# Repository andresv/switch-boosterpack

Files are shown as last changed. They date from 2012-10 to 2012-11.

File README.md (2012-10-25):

## Switch Launchpad Boosterpack

This is boosterpack for MSP430 Launchpad. It has SSD1306 based 128x64 pixel OLED display and 4 power MOSFET outputs. It is meant for switching various loads - for example pneumatic actuators or relays.

Software is written using Energia: https://github.com/energia/Energia

## LICENSE
### Software
This work is licensed under MIT license. http://opensource.org/licenses/MIT
### Hardware
This work is licensed under version 3.0 of the Creative Commons CC-BY-SA license.
http://creativecommons.org/licenses/by-sa/3.0/

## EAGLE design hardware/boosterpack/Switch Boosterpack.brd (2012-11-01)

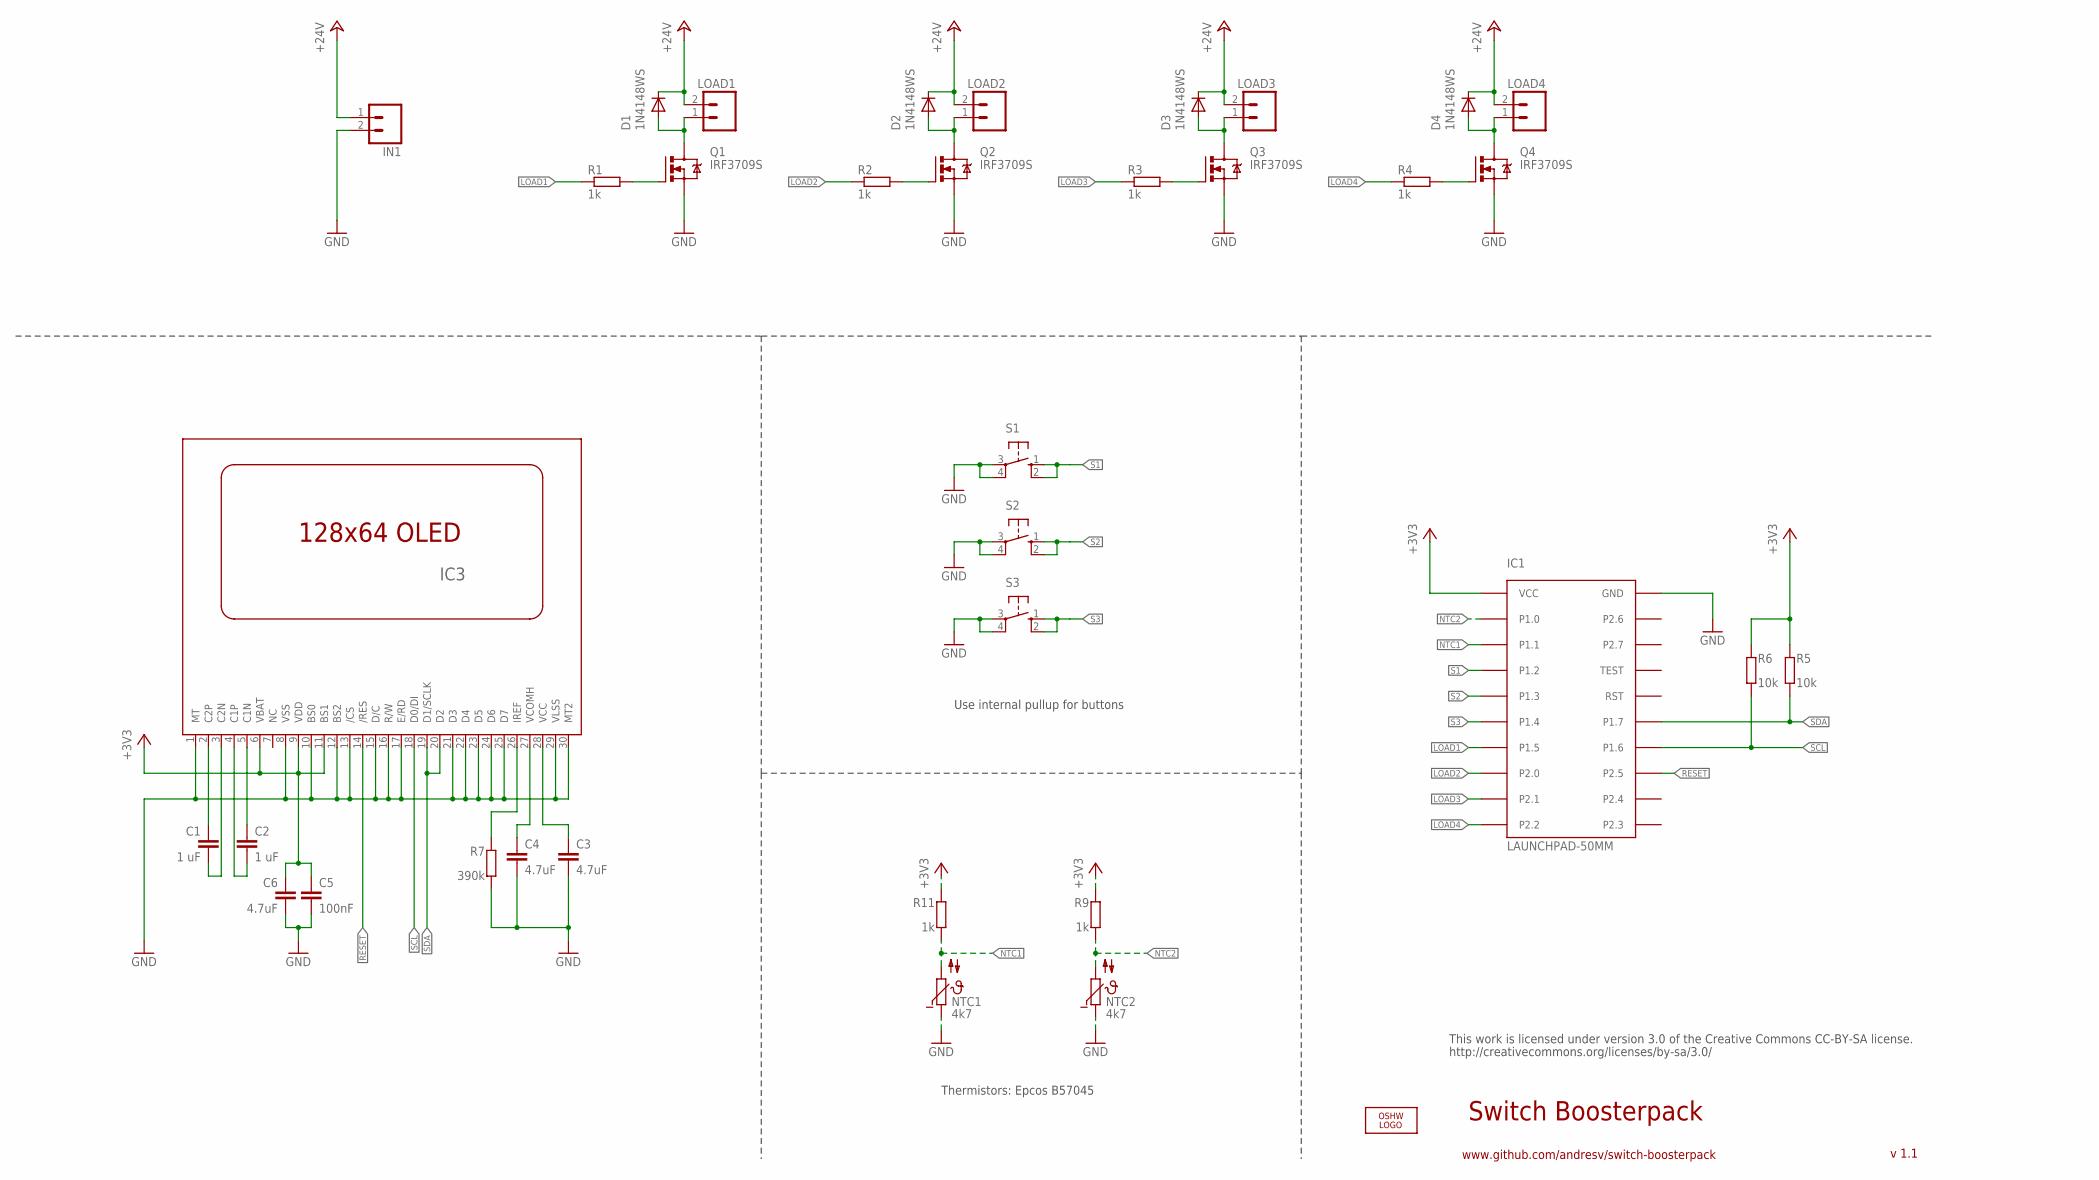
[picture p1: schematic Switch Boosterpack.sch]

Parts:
C1, C2: 1 uF; C0603
C3, C4, C6: 4.7uF; C0603
C5: 100nF; C0603
D1, D2, D3, D4: 1N4148WS; SOD323-W
IC1: LAUNCHPAD-50MM
IC3: UG-2864HSWEG01; 1X30-0.7MM
IN1: M025MM; SCREWTERMINAL-5MM-2
LOAD1, LOAD2, LOAD3, LOAD4: M025MM; SCREWTERMINAL-5MM-2
LOGO1: OSHW_LOGO_8MILX0350-NT; OSHW_8X350_NOTEXT
NTC1, NTC2: 4k7; N640
Q1, Q2, Q3, Q4: IRF3709S; D-PAK_TO252AA
R1, R2, R3, R4, R9, R11: 1k; R0603
R5, R6: 10k; R0603
R7: 390k; R0603
S1, S2, S3: 10-XX; B3F-10XX

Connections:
+3V3: C5.1, C6.1, IC1.VCC, IC3.6 (VBAT), IC3.9 (VDD), IC3.11 (BS1), R5.2, R6.2, R9.2, R11.2
+24V: D1.C, D2.C, D3.C, D4.C, IN1.1, LOAD1.2, LOAD2.2, LOAD3.2, LOAD4.2
GND: C3.2, C4.2, C5.2, C6.2, IC1.GND, IC3.1 (MT), IC3.8 (VSS), IC3.10 (BS0), IC3.12 (BS2), IC3.13 (/CS), IC3.15 (D/C), IC3.16 (R/W), IC3.17 (E/RD), IC3.21 (D3), IC3.22 (D4), IC3.23 (D5), IC3.24 (D6), IC3.25 (D7), IC3.29 (VLSS), IC3.30 (MT2), IN1.2, NTC1.1, NTC2.1, Q1.3 (S), Q2.3 (S), Q3.3 (S), Q4.3 (S), R7.1, S1.3, S1.4 (P1), S2.3, S2.4 (P1), S3.3, S3.4 (P1)
LOAD1: IC1.P1.5, R1.1
LOAD2: IC1.P2.0, R2.1
LOAD3: IC1.P2.1, R3.1
LOAD4: IC1.P2.2, R4.1
unnamed: D1.A, LOAD1.1, Q1.4 (D)
unnamed: Q1.1 (G), R1.2
unnamed: D2.A, LOAD2.1, Q2.4 (D)
unnamed: Q2.1 (G), R2.2
unnamed: D3.A, LOAD3.1, Q3.4 (D)
unnamed: Q3.1 (G), R3.2
unnamed: D4.A, LOAD4.1, Q4.4 (D)
unnamed: Q4.1 (G), R4.2
unnamed: C1.1, IC3.2 (C2P)
unnamed: C1.2, IC3.3 (C2N)
unnamed: C2.1, IC3.5 (C1N)
unnamed: C2.2, IC3.4 (C1P)
unnamed: C3.1, IC3.28 (VCC)
unnamed: C4.1, IC3.27 (VCOMH)
unnamed: IC3.26 (IREF), R7.2
NTC1: IC1.P1.1, NTC1.2, R11.1
NTC2: IC1.P1.0, NTC2.2, R9.1
RESET: IC1.P2.5, IC3.14 (/RES)
S1: IC1.P1.2, S1.1 (S), S1.2 (S1)
S2: IC1.P1.3, S2.1 (S), S2.2 (S1)
S3: IC1.P1.4, S3.1 (S), S3.2 (S1)
SCL: IC1.P1.6, IC3.18 (D0/DI), R6.1
SDA: IC1.P1.7, IC3.19 (D1/SCLK), IC3.20 (D2), R5.1

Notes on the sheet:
Switch Boosterpack
www.github.com/andresv/switch-boosterpack
v 1.1
This work is licensed under version 3.0 of the Creative Commons CC-BY-SA license.
http://creativecommons.org/licenses/by-sa/3.0/
Thermistors: Epcos B57045
Use internal pullup for buttons

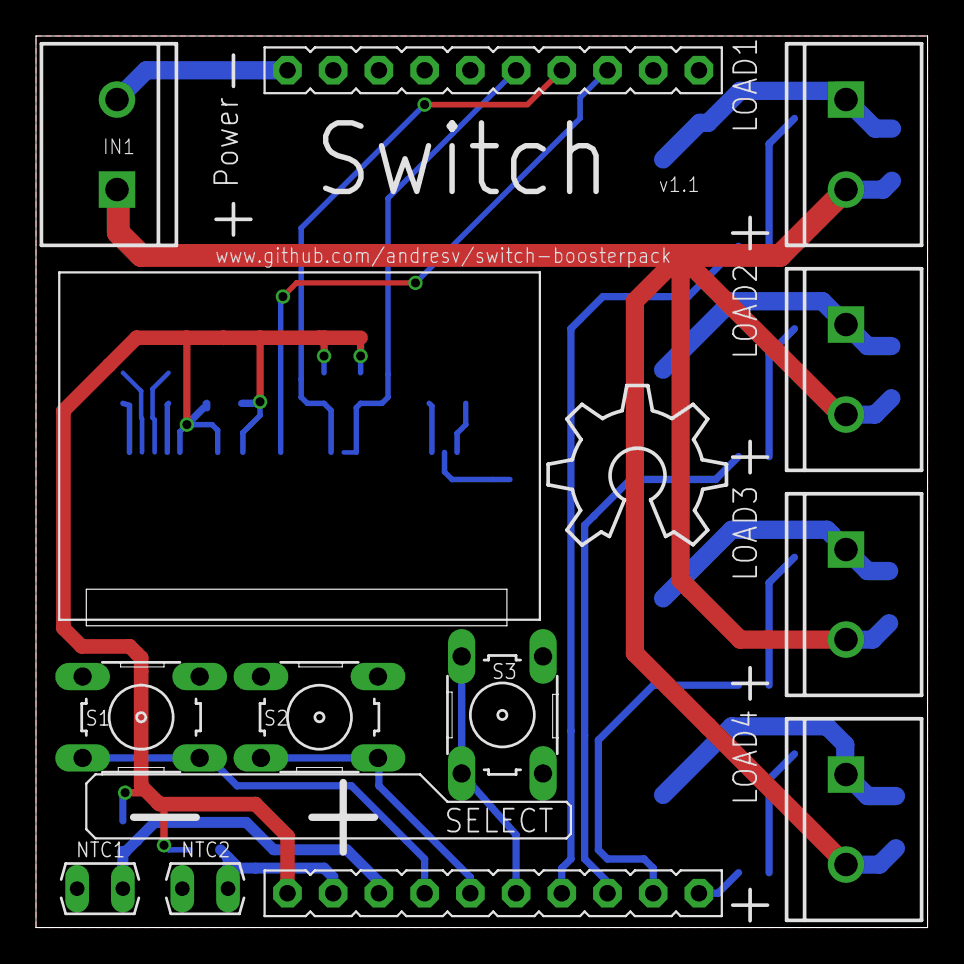
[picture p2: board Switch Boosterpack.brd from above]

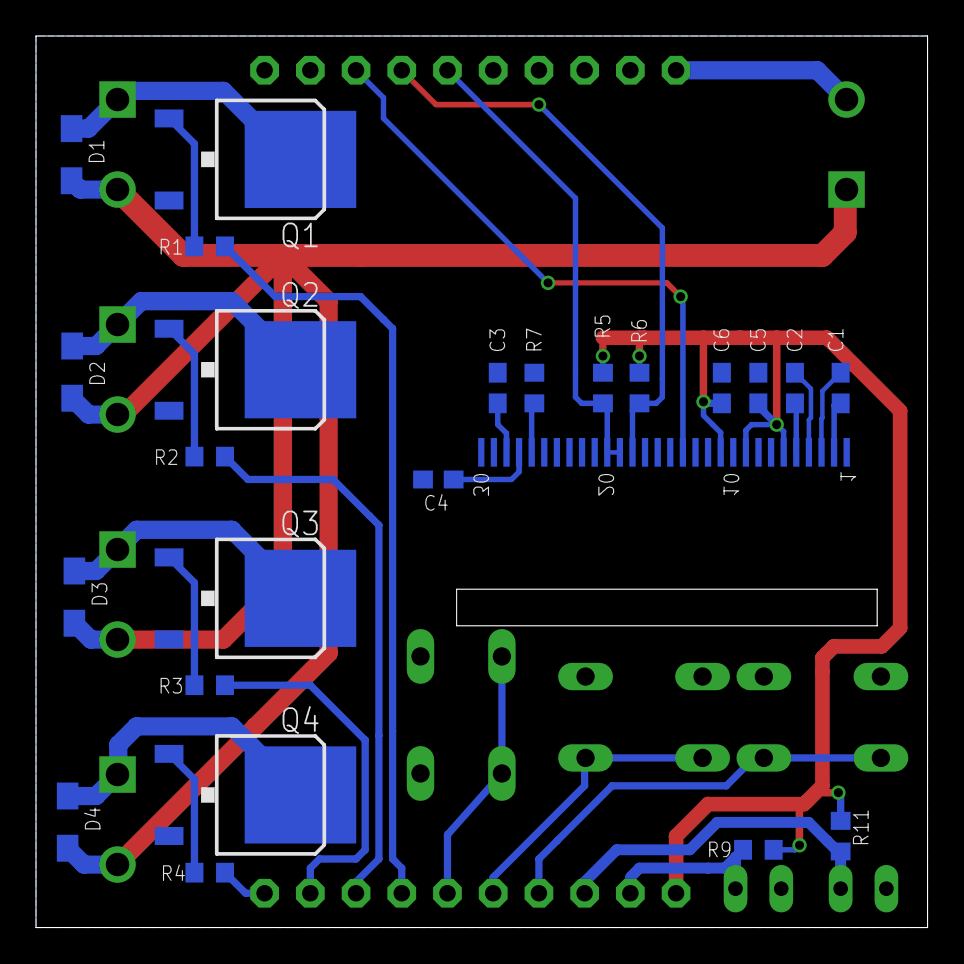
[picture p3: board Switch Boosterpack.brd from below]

Board: 2 copper layers, 49.5 x 49.5 mm, 36 parts (23 on the bottom side), 30 nets.

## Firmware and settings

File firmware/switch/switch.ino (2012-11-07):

/*
 * Copyright 2012 Andres Vahter
 * 
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
 * THE SOFTWARE IS PROVIDED "AS IS", WITHOUT WARRANTY OF ANY KIND,
 * EXPRESS OR IMPLIED, INCLUDING BUT NOT LIMITED TO THE WARRANTIES OF
 * MERCHANTABILITY, FITNESS FOR A PARTICULAR PURPOSE AND
 * NONINFRINGEMENT. IN NO EVENT SHALL THE AUTHORS OR COPYRIGHT HOLDERS BE
 * LIABLE FOR ANY CLAIM, DAMAGES OR OTHER LIABILITY, WHETHER IN AN ACTION
 * OF CONTRACT, TORT OR OTHERWISE, ARISING FROM, OUT OF OR IN CONNECTION
 * WITH THE SOFTWARE OR THE USE OR OTHER DEALINGS IN THE SOFTWARE.
 */

#include <Energia.h>
#include "MspFlash.h"
#include <stdlib.h>
#include "OLED.h"

#define TRUE 1
#define FALSE 0
#define ON 1
#define OFF 0

//https://github.com/energia/Energia/blob/master/hardware/msp430/libraries/MspFlash/examples/flash_readwrite/flash_readwrite.ino
#define flash SEGMENT_D

#define PLUS_BUTTON 4
#define MINUS_BUTTON 5
#define SELECT_BUTTON 6
#define LOAD1 7
#define LOAD2 8
#define LOAD3 9
#define LOAD4 10

#define NUMTEMPS 103 // NTC table
#define ROLLING_AVERAGE_SIZE 10

#define UPPER_HYSTERESIS 5
#define LOWER_HYSTERESIS 5

OLED oled(13, 0x3C);

int8_t current_temp_1;
int8_t set_temp_1;
int8_t current_temp_2;
int8_t set_temp_2;

uint16_t temp_1_rolling_buf[ROLLING_AVERAGE_SIZE];
uint16_t temp_2_rolling_buf[ROLLING_AVERAGE_SIZE];

bool hysteresis_1_raising = TRUE;
bool hysteresis_2_raising = TRUE;

uint8_t relay_states = 0; //0b000x xxx0

enum {
    STATE_DISPLAY,
    STATE_PLUS_BUTTON_PRESSED,
    STATE_MINUS_BUTTON_PRESSED,
    STATE_SELECT_BUTTON_PRESSED,
};

enum {
    MODE_DISPLAY,
    MODE_SET_1,
    MODE_SET_2,
};

uint8_t state = STATE_DISPLAY;
uint8_t mode = MODE_DISPLAY;
bool show_dot = 1;

// https://raw.github.com/reprap/firmware/master/createTemperatureLookup.py
// python createTemperatureLookup.py --r0=4700 --t0=25 --r1=0 --r2=1000 --beta=3950 --max-adc=1023
//      num steps were manualy set to 100 and adcref to 3.6 V
// http://hydraraptor.blogspot.com/2007/10/measuring-temperature-easy-way.html
// NTC 4.7k EPCOS B57045-K472-K

const short temptable[NUMTEMPS][2] = {
   {1, 554},
   {11, 277},
   {21, 231},
   {31, 206},
   {41, 190},
   {51, 178},
   {61, 168},
   {71, 160},
   {81, 154},
   {91, 148},
   {101, 143},
   {111, 138},
   {121, 134},
   {131, 130},
   {141, 127},
   {151, 123},
   {161, 120},
   {171, 118},
   {181, 115},
   {191, 113},
   {201, 110},
   {211, 108},
   {221, 106},
   {231, 104},
   {241, 102},
   {251, 100},
   {261, 98},
   {271, 96},
   {281, 95},
   {291, 93},
   {301, 91},
   {311, 90},
   {321, 88},
   {331, 87},
   {341, 85},
   {351, 84},
   {361, 82},
   {371, 81},
   {381, 80},
   {391, 78},
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
};

int convert_raw_to_celsius(int rawtemp) {
    int current_celsius = 0;
    int i = 0;

    for (i=1; i < NUMTEMPS; i++) {
        if (temptable[i][0] > rawtemp) {
            int realtemp  = temptable[i-1][1] + (rawtemp - temptable[i-1][0]) * (temptable[i][1] - temptable[i-1][1]) / (temptable[i][0] - temptable[i-1][0]);
            if (realtemp > 255) {
                realtemp = 255;
            }

            current_celsius = realtemp;
            break;
        }
    }

    // Overflow: We just clamp to 0 degrees celsius
    if (i == NUMTEMPS)  {
        current_celsius = 1000;
    }

    return current_celsius;
}

inline uint16_t calc_average(uint16_t* buf, bool filled) {
    if (filled) {
        uint8_t i;
        uint16_t sum = 0;
        for (i=0; i<ROLLING_AVERAGE_SIZE; i++) {
            sum += buf[i];
        }
        return sum/ROLLING_AVERAGE_SIZE;
    }
    else {
        return buf[0];
    }
}

uint16_t temp_1_rolling_average(uint16_t rawtemp) {
    static uint8_t index = 0;
    static bool filled = FALSE;

    temp_1_rolling_buf[index] = rawtemp;
    index++;
    if (index == ROLLING_AVERAGE_SIZE) {
        index = 0;
        filled = TRUE;
    }

    return calc_average(temp_1_rolling_buf, filled);
}

uint16_t temp_2_rolling_average(uint16_t rawtemp) {
    static uint8_t index = 0;
    static bool filled = FALSE;

    temp_2_rolling_buf[index] = rawtemp;
    index++;
    if (index == ROLLING_AVERAGE_SIZE) {
        index = 0;
        filled = TRUE;
    }

    return calc_average(temp_2_rolling_buf, filled);
}

int read_temp_1() {
    uint16_t rawtemp = analogRead(A1);
    return convert_raw_to_celsius(temp_1_rolling_average(rawtemp));
}

int read_temp_2() {
    uint16_t rawtemp = analogRead(A0);
    return convert_raw_to_celsius(temp_2_rolling_average(rawtemp));
}

void read_temp_sensors() {
    current_temp_1 = read_temp_1();
    oled.set_cursor(10, 5, LARGE_FONT);
    oled.write("%3i %3i", current_temp_1, set_temp_1);
    
    current_temp_2 = read_temp_2();
    oled.set_cursor(10, 2, LARGE_FONT);
    oled.write("%3i %3i", current_temp_2, set_temp_2);
}

void display_relay_state(uint8_t relay_nr, bool on) {
    if (on) {
        relay_states |= (1<<relay_nr);
        oled.write("o");
    }
    else {
        relay_states &= ~(1<<relay_nr);
        oled.write(".");
    }
}

void switch_relay(uint8_t relay_nr, bool on) {
    // Notice that LOAD outputs are inverted
    // LOW is ON
    // HIGH is OFF
    // Thats why there is such a 'nice' bit twiddling
    switch (relay_nr) {
        case 1:
            oled.set_cursor(120, 7, SMALL_FONT);
            display_relay_state(relay_nr, on);
            digitalWrite(LOAD1, ((relay_states ^ (1 << 1)) >> 1) & 0x01);
            break;
        case 2:
            oled.set_cursor(120, 5, SMALL_FONT);
            display_relay_state(relay_nr, on);
            digitalWrite(LOAD2, ((relay_states ^ (1 << 2)) >> 2) & 0x01);
            break;
        case 3:
            oled.set_cursor(120, 3, SMALL_FONT);
            display_relay_state(relay_nr, on);
            digitalWrite(LOAD3, ((relay_states ^ (1 << 3)) >> 3) & 0x01);
            break;
        case 4:
            oled.set_cursor(120, 1, SMALL_FONT);
            display_relay_state(relay_nr, on);
            digitalWrite(LOAD4, ((relay_states ^ (1 << 4)) >> 4) & 0x01);
            break;
    }
}

void save_set_values() {
    int8_t buf[2] = {set_temp_1, set_temp_2};
    Flash.erase(flash);
    Flash.write(flash, (unsigned char*)buf, 2);
}

void restore_set_values() {
    Flash.read(flash, (unsigned char*)&set_temp_1, 1);
    Flash.read(flash+1, (unsigned char*)&set_temp_2, 1);
}

void setup() {
    restore_set_values();

    oled.init();
    oled.clear();
    
    oled.set_cursor(15, 7, SMALL_FONT);
    oled.write("current       set");

    oled.set_cursor(10, 5, LARGE_FONT);
    oled.write("%3i %3i", current_temp_1, set_temp_1);

    oled.set_cursor(10, 2, LARGE_FONT);
    oled.write("%3i %3i", current_temp_2, set_temp_2);

    pinMode(LOAD1, OUTPUT);
    pinMode(LOAD2, OUTPUT);
    pinMode(LOAD3, OUTPUT);
    pinMode(LOAD4, OUTPUT);
    switch_relay(1, OFF);
    switch_relay(2, OFF);
    switch_relay(3, OFF);
    switch_relay(4, OFF);
    
    pinMode(PLUS_BUTTON, INPUT_PULLUP);
    pinMode(MINUS_BUTTON, INPUT_PULLUP);
    pinMode(SELECT_BUTTON, INPUT_PULLUP);

    pinMode(A0, INPUT);
    pinMode(A1, INPUT);
}

void loop() {
    read_temp_sensors();

    if (digitalRead(PLUS_BUTTON) == LOW) {
        state = STATE_PLUS_BUTTON_PRESSED;
        delay(10);
    }
    else if (digitalRead(MINUS_BUTTON) == LOW) {
        state = STATE_MINUS_BUTTON_PRESSED;
        delay(10);
    }
    else if (digitalRead(SELECT_BUTTON) == LOW) {
        state = STATE_SELECT_BUTTON_PRESSED;
        delay(10);
    }

    switch(state) {
        case STATE_PLUS_BUTTON_PRESSED:
            if (mode == MODE_SET_1) {
                set_temp_1++;
            }
            else if (mode == MODE_SET_2) {
                set_temp_2++;
            }
            state = STATE_DISPLAY;
            break;

        case STATE_MINUS_BUTTON_PRESSED:
            if (mode == MODE_SET_1) {
                set_temp_1--;
            }
            else if (mode == MODE_SET_2) {
                set_temp_2--;
            }
            state = STATE_DISPLAY;
            break;

        case STATE_SELECT_BUTTON_PRESSED:
            if (mode == MODE_DISPLAY) {
                mode = MODE_SET_1;
            }
            else if (mode == MODE_SET_1) {
                mode = MODE_SET_2;
            }
            else {
                save_set_values();
                mode = MODE_DISPLAY;
            }

            delay(500); // wait a little, otherwise we might get back to MODE_SET_1 too soon

            state = STATE_DISPLAY;
            break;

        case STATE_DISPLAY:
            // show blinking dot
            oled.set_cursor(0, 7, SMALL_FONT);
            if (show_dot == 1) {
                show_dot = 0;
                oled.write(" ");
            }
            else {
                show_dot = 1;
                oled.write(".");
            }

            // show temperatures
            if (mode == MODE_SET_1) {
                oled.set_cursor(10, 5, LARGE_FONT);
                oled.write("%3i    ", current_temp_1);
                oled.set_cursor(10, 5, LARGE_FONT);
                oled.write("%3i %3i", current_temp_1, set_temp_1);
            }
            else if (mode == MODE_SET_2) {
                oled.set_cursor(10, 2, LARGE_FONT);
                oled.write("%3i    ", current_temp_2);
                oled.set_cursor(10, 2, LARGE_FONT);
                oled.write("%3i %3i", current_temp_2, set_temp_2);
            }

            //---------------------------------------------------------------
            // 1 ON-OFF regulator
            //---------------------------------------------------------------
            // upper point
            if (hysteresis_1_raising && (current_temp_1 >= (set_temp_1 + UPPER_HYSTERESIS))) {
                hysteresis_1_raising = FALSE;
            }
            // lower point
            else if (!hysteresis_1_raising && (current_temp_1 <= (set_temp_1 - LOWER_HYSTERESIS))) {
                hysteresis_1_raising = TRUE;
            }
            // raising
            if (hysteresis_1_raising) {
                switch_relay(1, ON);
                switch_relay(2, ON);
            }
            // falling
            else {
                switch_relay(1, OFF);
                switch_relay(2, OFF);
            }

            //---------------------------------------------------------------
            // 2 ON-OFF regulator
            //---------------------------------------------------------------
            // upper point
            if (hysteresis_2_raising && (current_temp_2 >= (set_temp_2 + UPPER_HYSTERESIS))) {
                hysteresis_2_raising = FALSE;
            }
            // lower point
            else if (!hysteresis_2_raising && (current_temp_2 <= (set_temp_2 - LOWER_HYSTERESIS))) {
                hysteresis_2_raising = TRUE;
            }
            // raising
            if (hysteresis_2_raising) {
                switch_relay(3, ON);
                switch_relay(4, ON);
            }
            // falling
            else {
                switch_relay(3, OFF);
                switch_relay(4, OFF);
            }

            break;
    }
}

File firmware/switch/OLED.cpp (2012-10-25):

/*
 * Copyright 2012 Andres Vahter
 * 
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
 * THE SOFTWARE IS PROVIDED "AS IS", WITHOUT WARRANTY OF ANY KIND,
 * EXPRESS OR IMPLIED, INCLUDING BUT NOT LIMITED TO THE WARRANTIES OF
 * MERCHANTABILITY, FITNESS FOR A PARTICULAR PURPOSE AND
 * NONINFRINGEMENT. IN NO EVENT SHALL THE AUTHORS OR COPYRIGHT HOLDERS BE
 * LIABLE FOR ANY CLAIM, DAMAGES OR OTHER LIABILITY, WHETHER IN AN ACTION
 * OF CONTRACT, TORT OR OTHERWISE, ARISING FROM, OUT OF OR IN CONNECTION
 * WITH THE SOFTWARE OR THE USE OR OTHER DEALINGS IN THE SOFTWARE.
 */


/*
 * This driver is based on www.43oh.com 128x64 OLED Booster Pack driver:
 * http://www.43oh.com/2011/11/the-terminal-128x64-oled-booster-pack/
 *
 * Original driver is heaviliy modified by Andres Vahter in order to work
 * with Energia environment and with I2C protocol.
*/

#include <Energia.h>
#include <Wire.h>
#include "OLED.h"
#include "CourierNew_14x15.h"
#include "CourierNew_5x7.h"

OLED::OLED(uint8_t reset_pin, uint8_t i2c_address) {
    p_reset_pin = reset_pin;
    p_i2c_address = i2c_address;

    p_row = 0;
    p_column = 0;
    p_column_increment_small_font = 0;
    p_column_increment_large_font = 0;
    p_column_increment_flag = NO_FONT;

    //      4294967296      // 32 bit unsigned max
    dv[0] = 1000000000;     // +0
    dv[1] =  100000000;     // +1
    dv[2] =   10000000;     // +2
    dv[3] =    1000000;     // +3
    dv[4] =     100000;     // +4
    //           65535      // 16 bit unsigned max     
    dv[5] =      10000;     // +5
    dv[6] =       1000;     // +6
    dv[7] =        100;     // +7
    dv[8] =         10;     // +8
    dv[9] =          1;     // +9
        
}

void OLED::init() {
    pinMode(p_reset_pin, OUTPUT);
    digitalWrite(p_reset_pin, HIGH);
    delay(100);

    Wire.begin();

    digitalWrite(p_reset_pin, HIGH);
    // VDD (3.3V) goes high at start, lets just chill for a ms
    delay(1);
    digitalWrite(p_reset_pin, LOW);
    delay(10);
    digitalWrite(p_reset_pin, HIGH);

    send_command(0xae); // turn off oled panel 
    send_command(0x00); // set low column address 
    send_command(0x10); // set high column address 
    send_command(0x40); // set start line address 
    send_command(0x81); // set contrast control register 
    send_command(0xcf); 
    send_command(0xa1); // set segment re-map 95 to 0 
    send_command(0xa6); // set normal display 
    send_command(0xa8); // set multiplex ratio(1 to 64) 
    send_command(0x3f); // 1/64 duty 
    send_command(0xd3); // set display offset 
    send_command(0x00); // not offset 
    send_command(0xd5); // set display clock divide ratio/oscillator frequency 
    send_command(0x80); // set divide ratio 
    send_command(0xd9); // set pre-charge period 
    send_command(0xf1); 
    send_command(0xda); // set com pins hardware configuration 
    send_command(0x12); 
    send_command(0xdb); // set vcomh 
    send_command(0x40); 
    send_command(0x8d); // set Charge Pump enable/disable 
    send_command(0x14); // set(0x10) disable 
    send_command(0xaf); // turn on oled panel
    
    clear();            // Clear Screen
}

void OLED::clear() {
    fill_ram(0x00);
}

void OLED::set_cursor(uint8_t column, uint8_t row, uint8_t size_flag) {
    p_row = row;
    p_column_increment_flag = size_flag;
  
    if (p_column_increment_flag == SMALL_FONT)
        p_column_increment_small_font = column;
  
    if (p_column_increment_flag == LARGE_FONT)
        p_column_increment_large_font = column;
}

void OLED::write(char *format, ...) {
    char c;
    int i, val;
    int8_t padding_len;
    long n;
    
    va_list a;
    va_start(a, format);
    while (c = *format++) {
        if (c == '%') {
            c = *format++;
            // '1' is 49 '2' is 50 .. '9' is 57
            // '1' - 48 = 0x01 which is real number, not ASCII number
            padding_len = c-48;
            // we found padding so now check format string type
            if ((uint8_t)padding_len >= 1 && (uint8_t)padding_len <= 9) {
                c = *format++;
            }

            switch (c) {
                case 's':                       // String
                    puts(va_arg(a, char*));
                    break;
                case 'c':                       // Char
                    putc(va_arg(a, char));
                    break;
                case 'i':                       // 16 bit Integer
                case 'd':                       // 16 bit Integer
                case 'u':                       // 16 bit Unsigned
                    i = va_arg(a, int);
                    if ((uint8_t)padding_len >= 1 && (uint8_t)padding_len <= 9) {
                        val = i;
                        while (val != 0) {
                            val = val / 10;
                            padding_len--;
                        }

                        if (padding_len > 0) {
                            if (i <= 0) {
                                padding_len--; // - sign already pads 1 place and 0 is special
                            }

                            for (int i = 0; i < (uint8_t)padding_len; ++i) {
                                putc(' ');
                            }
                        }
                    }

                    if (c == 'i' && i < 0) {
                        i = -i;
                        putc('-');
                    }

                    xtoa((unsigned)i, dv + 5);
                    break;
                case 'l':                       // 32 bit Long
                case 'n':                       // 32 bit uNsigned loNg
                    n = va_arg(a, long);
                    if (c == 'l' &&  n < 0) n = -n, putc('-');
                    xtoa((unsigned long)n, dv);
                    break;
                case 'x':                       // 16 bit heXadecimal
                    i = va_arg(a, int);
                    puth(i >> 12);
                    puth(i >> 8);
                    puth(i >> 4);
                    puth(i);
                    break;
                case 0: return;
                default: goto bad_fmt;
            }
        }
        else {
            bad_fmt:    putc(c);            
        }
    }
    va_end(a);
}

void OLED::putc(uint8_t c) {
    if (p_column_increment_flag == SMALL_FONT) {
        fill_ram_font_small(c-32, p_column_increment_small_font, p_row);
        p_column_increment_small_font = p_column_increment_small_font + SMALL_FONT_WIDTH;
    }

    if (p_column_increment_flag == LARGE_FONT) {
        fill_ram_font(c, p_column_increment_large_font, p_row, LARGE_FONT_SPAN, LARGE_FONT_WIDTH);
        p_column_increment_large_font = p_column_increment_large_font + LARGE_FONT_WIDTH;
    } 
}
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

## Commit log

2012-09-23 Added initial EAGLE schematic and board files.
    [Switch Boosterpack.brd, Switch Boosterpack.sch]
2012-10-20 Tweaked silkscreen and made OLED ribbon cutoff longer.
    [Switch Boosterpack.brd, Switch Boosterpack.sch]
2012-10-21 Fixed load 1 + sign position.
    [Switch Boosterpack.brd]
2012-10-21 BS0 is now tied to GND, C1, C2 are 1 uF and R7 is 390k.
    Those are main v1.0 errors. They must be fixed otherwise v1.0 boards are not working.
    [Switch Boosterpack.brd, Switch Boosterpack.sch]
2012-10-21 Added initial firmware.
    OLED driver for Energia environment is working.
2012-10-25 Added padding to format strings.
    printf(" %4u", 56);
    printf(" %4i", -56);
2012-10-25 Initial user interface with buttons ready.
2012-11-01 Fixed schematic, instead of N channel FET there were P channel FET on schematic.
    So actually 1.0 board MOSFET side was messed up. Now it is correct. P channel FET was used in "N channel configuration".
    [Switch Boosterpack.brd, Switch Boosterpack.sch]
2012-11-06 Added NTC temperature sensor readings.
2012-11-06 Now set temperature parameters are saved to flash.
2012-11-07 Now 10 element average temperature is shown to reduce jumping.
2012-11-07 Fixed typo in average calculation.
    [switch.ino]
2012-11-07 Added MOSFET switching to switch_relay(..) function.
2012-11-07 Added on/off regulator with hysteresis.
